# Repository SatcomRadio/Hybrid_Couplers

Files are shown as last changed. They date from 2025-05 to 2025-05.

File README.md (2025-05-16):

# Hybrid coupler boards for making circular polarization

This repo consists of different boards that use different devices to get [circular polarized](https://satcomradio.github.io/#/antennas/polarization) antennas. 

#### Please make sure to visit the [satcom radio website](https://satcomradio.github.io/) for more information

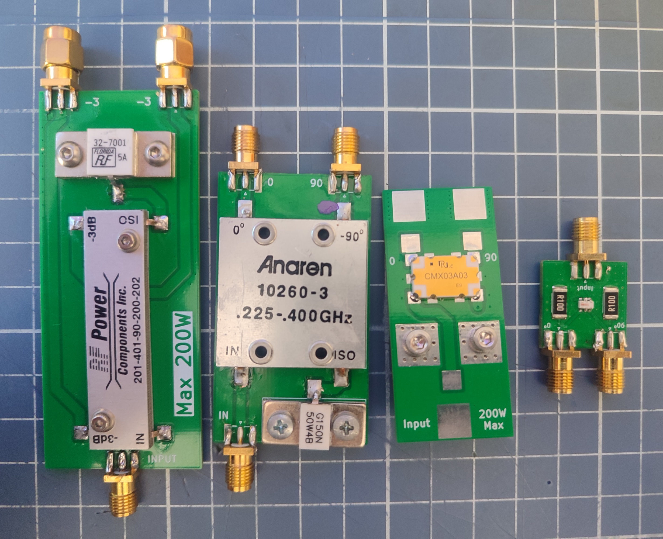
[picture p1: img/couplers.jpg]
couplers


All the PCB boards have a version that where you can use SMA connectors or soldered wires.  
If you want to use the SMA connector boards, you will need to buy:

```
3x SMA connectors for PCB with 1.6mm spacing (aliexpress.com/item/10000000835065.html)

```

Important!

You must connect them correctly! Each port has to be a "dipole".  
Depending on their orientation you will get RHCP or LHCP.

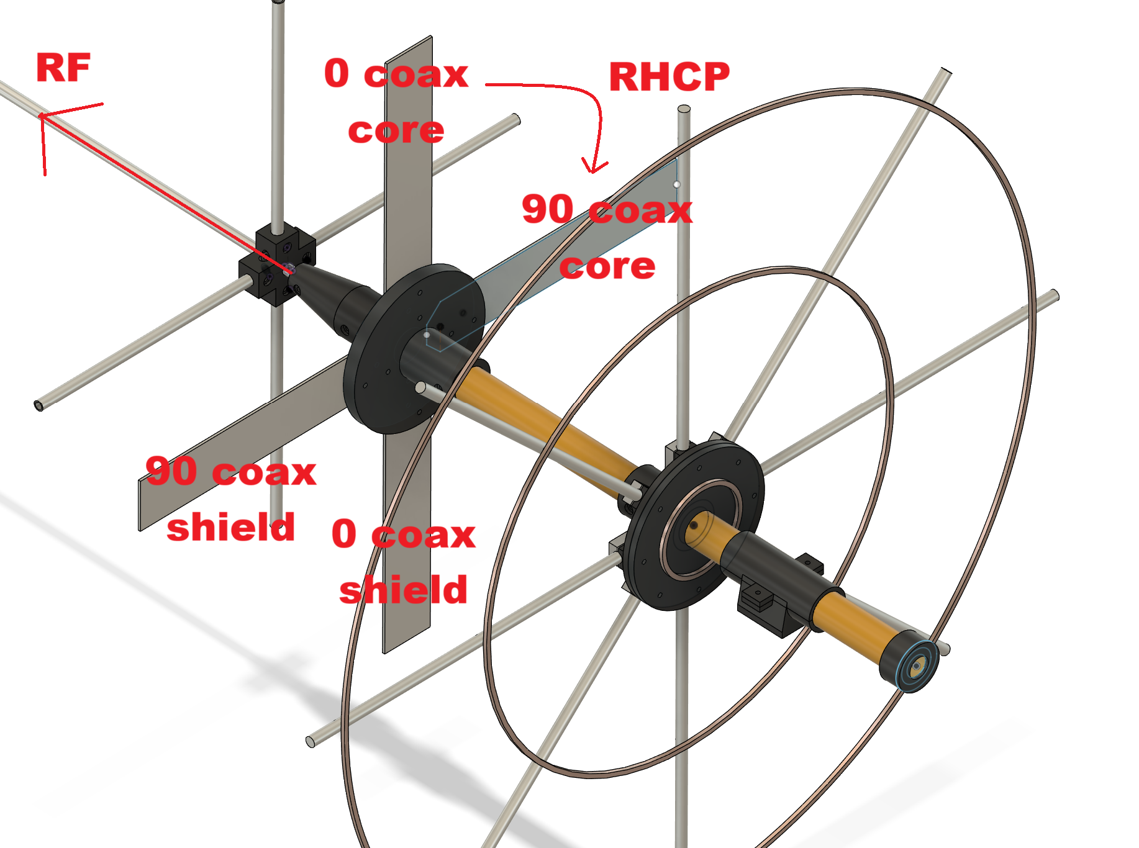
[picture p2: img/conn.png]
connection


------

## Ordering the PCB:

Download the Gerber file you want from this repo and order it a jlcpcb with the default options.  
The only option I've changed is to remove the manufacture code mark

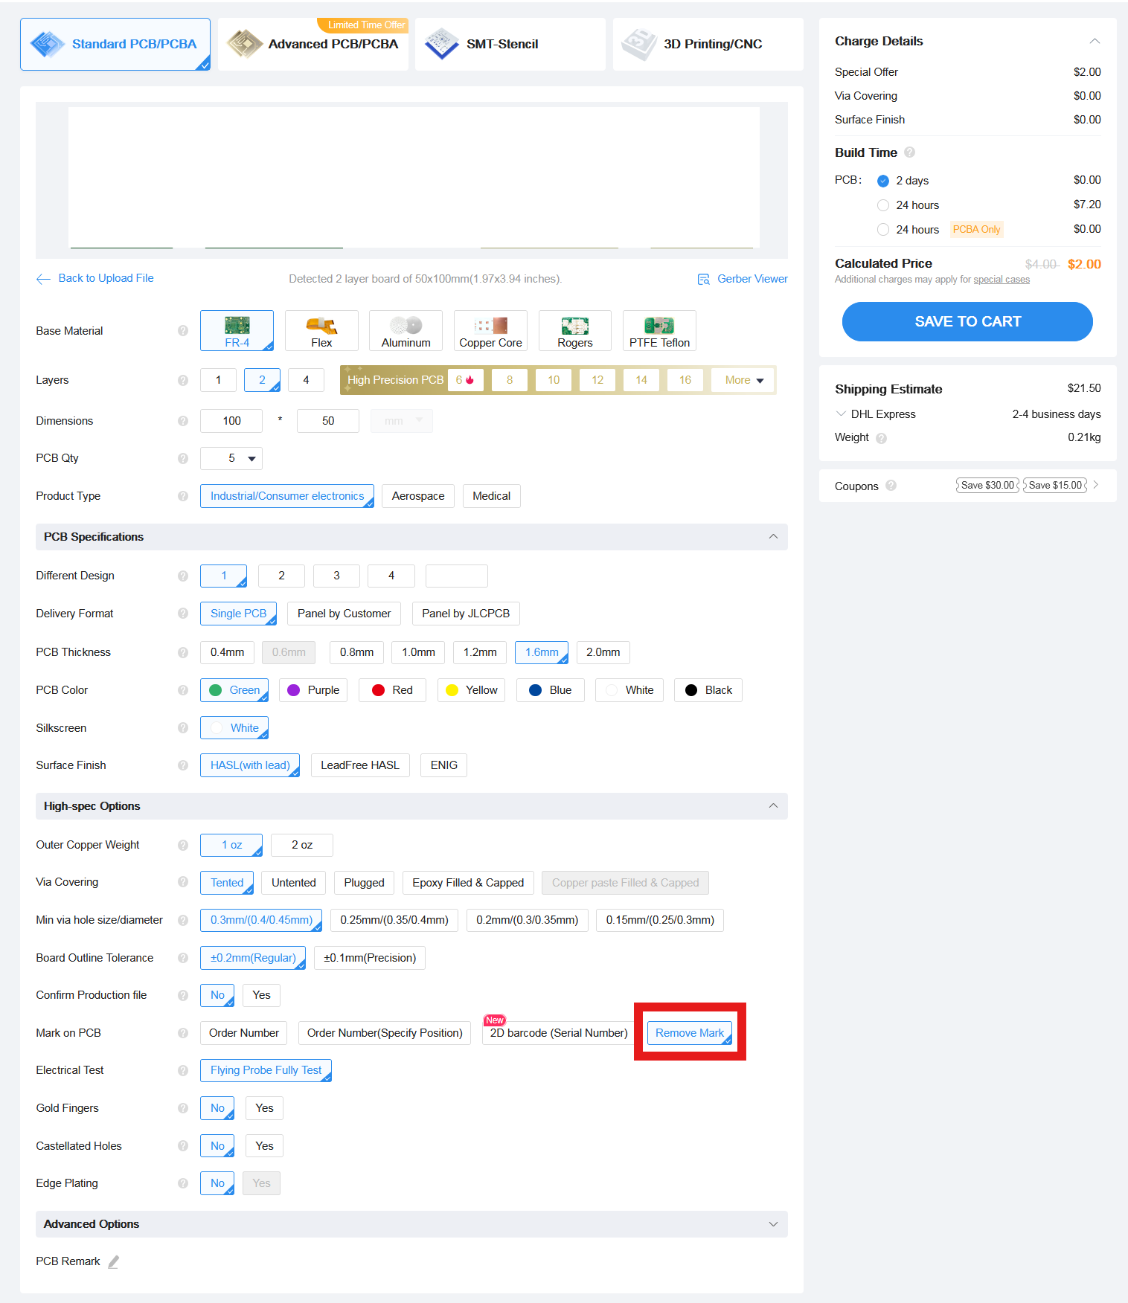
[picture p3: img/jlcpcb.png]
jlcpcb


------

## CMX03A03:

- [SMA version](./GERBER-CmxSma.zip)  
- [Soldered wires version](./GERBER-CmxRf.zip)

Most compact option for high power. Can handle 200W

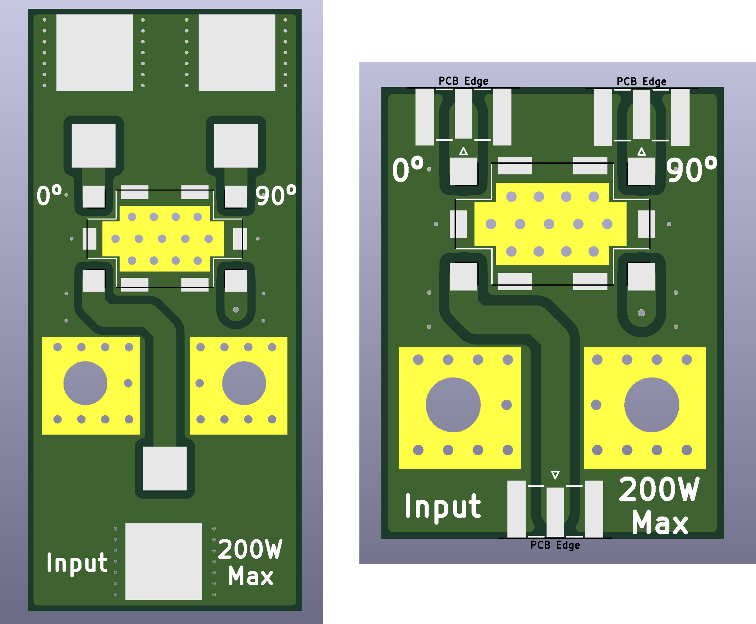
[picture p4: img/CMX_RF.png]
cmx


### BOM:

```
1x CMX03A03 (aliexpress.com/item/1005008506296292.html)
1x G150N 50 ohm RF load (aliexpress.com/item/32909755238.html)

```
----

## RF Power:

- [SMA version](./GERBER-RfPowerSma.zip)  
- [Soldered wires version](./GERBER-RfPowerRf.zip)

Can handle 200W.  
Probably an old model made by "Florida RF Labs"
There's no information about this coupler but it's usually sold with a 50 ohm resistance for free.

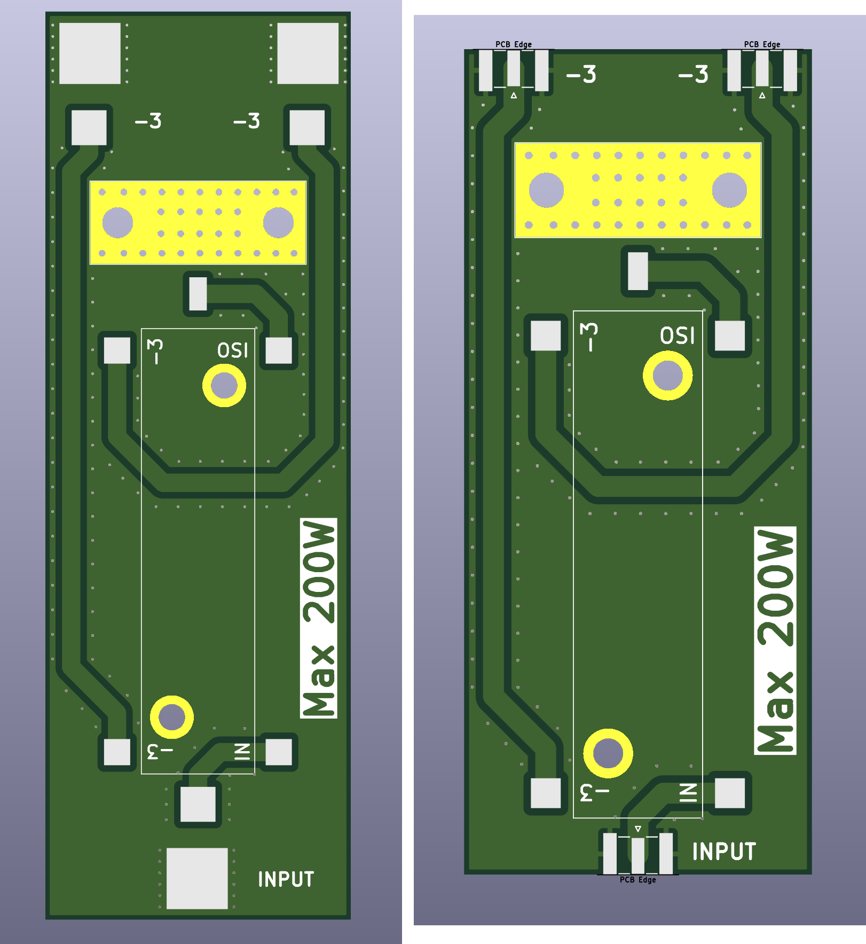
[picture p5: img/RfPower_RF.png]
rfpower


### BOM:

```
1x RF Power coupler (aliexpress.com/item/32886665884.html)

This resistance is often given for free when you buy the coupler:
1x RF 32-7001 50 ohm RF load (aliexpress.com/i/1005006266356008.html)

```
----

## Anaren 10260-3:

- [SMA version](./GERBER-AnarenSma.zip)  
- [Soldered wires version](./GERBER-AnarenRf.zip)

Can handle 250W.  
Outdated so it's difficult to find. Usually it's sold on ebay.

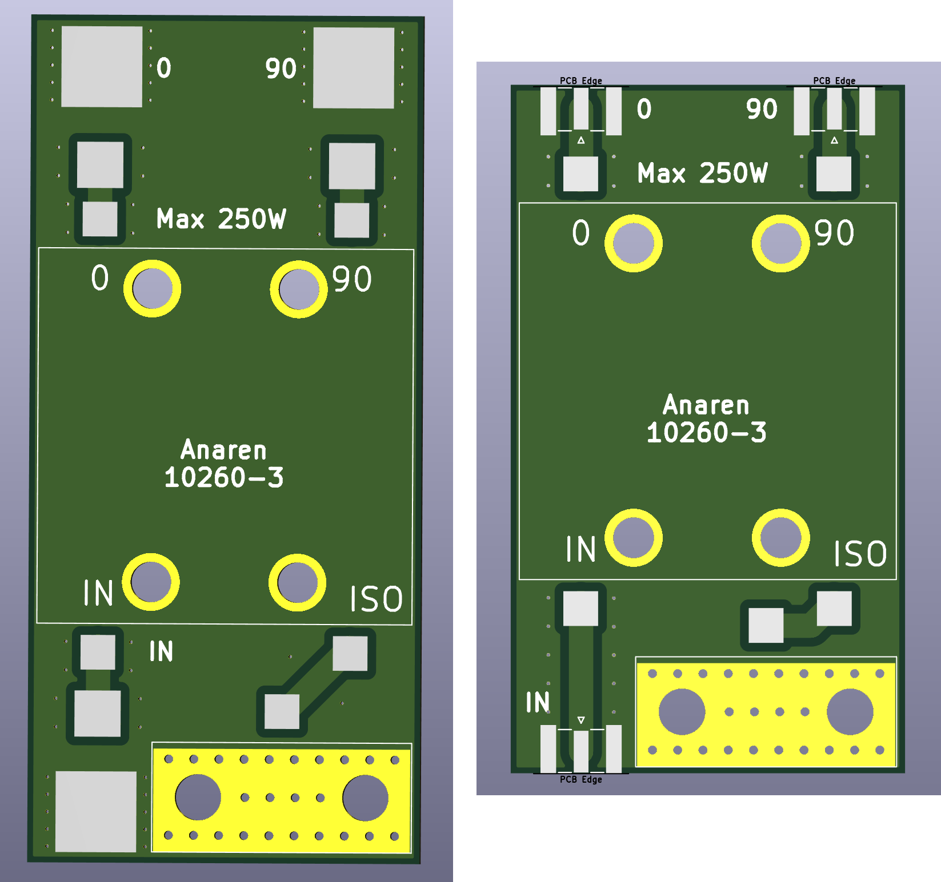
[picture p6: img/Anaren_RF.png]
anaren


### BOM:

```
1x Anaren 10260-3
1x G150N 50 ohm RF load (aliexpress.com/item/32909755238.html)

```
----

## QCN3:

- [SMA version](./GERBER-CmxSma.zip)  
- [Soldered wires version](./GERBER-Qcn3Rf.zip)

Most compact option. Can handle 15W.  
To be used only with handheld radios.

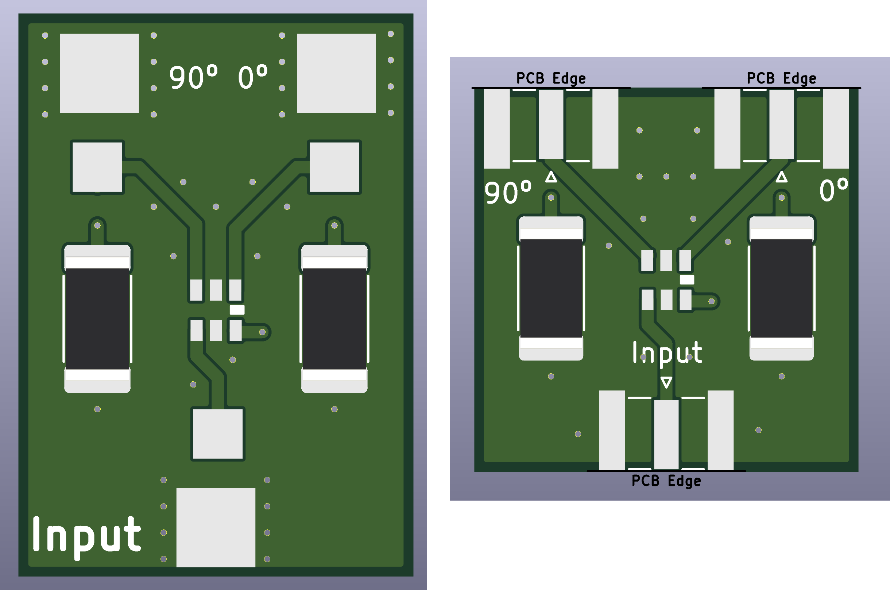
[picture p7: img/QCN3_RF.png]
qcn3


### BOM:

```
1x QCN-3 (aliexpress.com/item/1005002788551103.html)
2x SMD resistor 2512 100Ω 2W resistor (https://es.aliexpress.com/item/1005007255020731.html)

```
----

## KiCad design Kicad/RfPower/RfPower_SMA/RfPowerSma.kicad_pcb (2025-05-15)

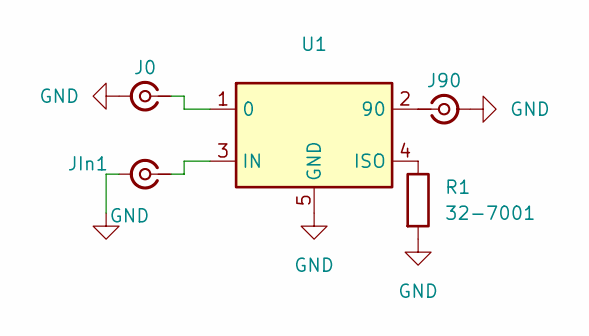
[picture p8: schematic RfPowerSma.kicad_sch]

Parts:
J0, J90: SMA_Samtec_SMA-J-P-X-ST-EM1_EdgeMount
JIn1: SMA_Samtec_SMA-J-P-X-ST-EM1_EdgeMount
R1: 32-7001
U1: RfPower

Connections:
GND: J0.2 (Ext), J90.2 (Ext), JIn1.2 (Ext), R1.2, U1.5 (GND)
unnamed: J0.1 (In), U1.1 (0)
unnamed: J90.1 (In), U1.2 (90)
unnamed: JIn1.1 (In), U1.3 (IN)
unnamed: R1.1, U1.4 (ISO)

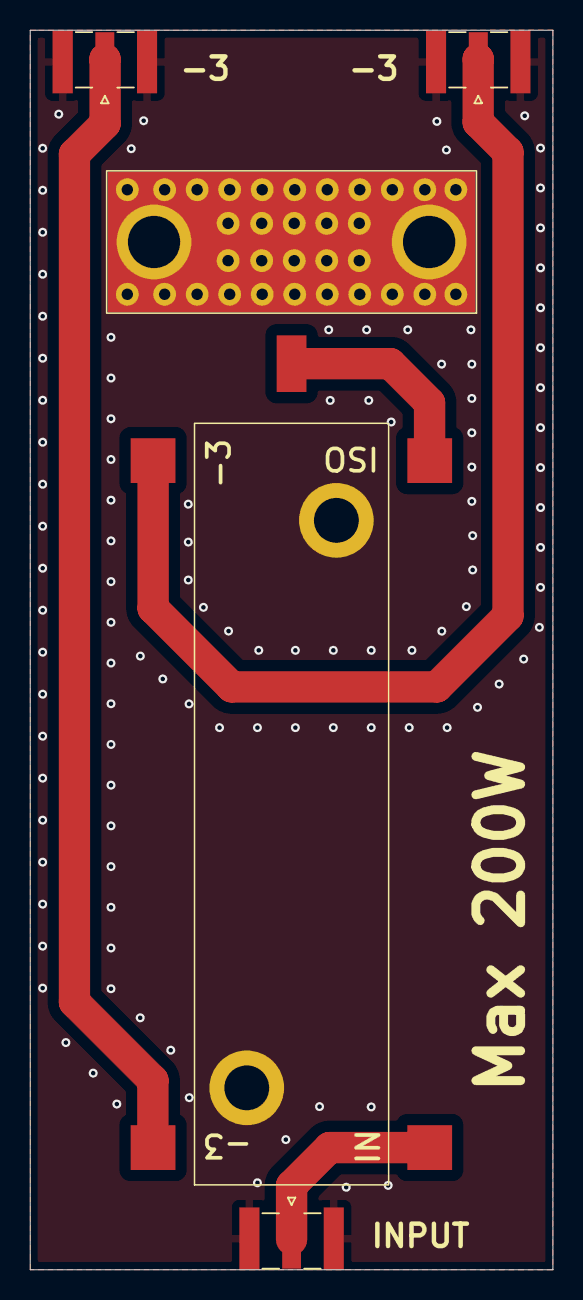
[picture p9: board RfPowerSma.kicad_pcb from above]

Board: 2 copper layers, 35.0 x 83.0 mm, 5 parts (0 on the bottom side), 5 nets.

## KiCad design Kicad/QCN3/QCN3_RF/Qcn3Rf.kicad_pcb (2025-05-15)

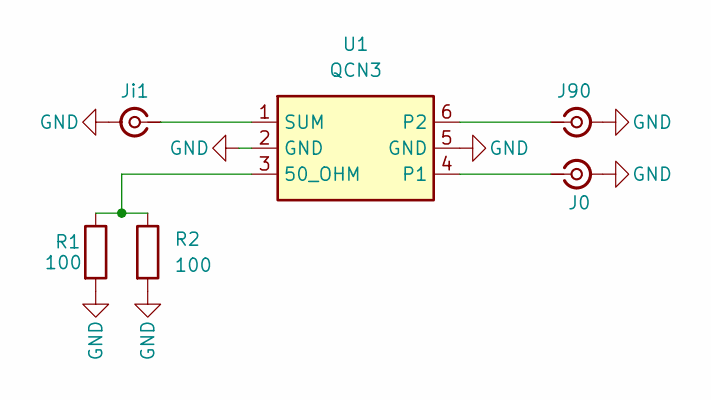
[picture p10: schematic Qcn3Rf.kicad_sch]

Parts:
J0, J90: Conn_Coaxial_Small; Wire connector_S
Ji1: Conn_Coaxial_Small; Wire connector_S
R1, R2: 100; R_2512_6332Metric_Pad1.40x3.35mm_HandSolder
U1: QCN3

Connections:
GND: J0.2 (Ext), J90.2 (Ext), Ji1.2 (Ext), R1.2, R2.2, U1.2 (GND), U1.5 (GND)
unnamed: J0.1 (In), U1.4 (P1)
unnamed: J90.1 (In), U1.6 (P2)
unnamed: Ji1.1 (In), U1.1 (SUM)
unnamed: R1.1, R2.1, U1.3 (50_OHM)

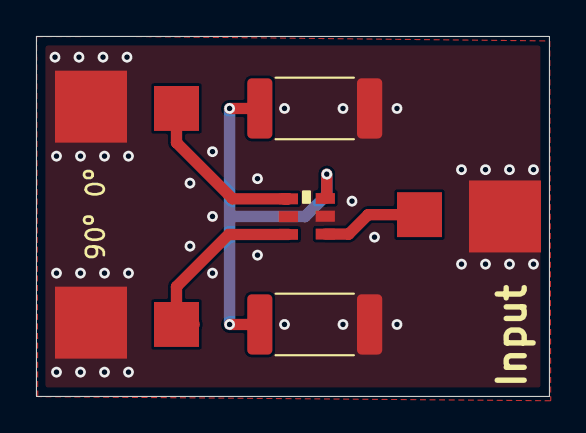
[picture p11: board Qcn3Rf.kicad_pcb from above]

Board: 2 copper layers, 28.5 x 20.0 mm, 6 parts (0 on the bottom side), 5 nets.

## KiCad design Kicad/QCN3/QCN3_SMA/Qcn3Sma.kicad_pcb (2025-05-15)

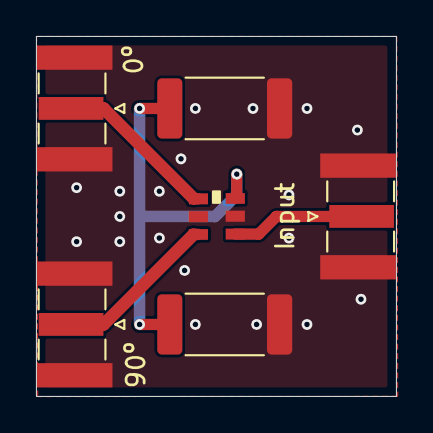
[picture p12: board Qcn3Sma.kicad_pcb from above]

Board: 2 copper layers, 20.0 x 20.0 mm, 6 parts (0 on the bottom side), 5 nets.

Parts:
0º, 90º: Conn_Coaxial_Small; SMA_Samtec_SMA-J-P-X-ST-EM1_EdgeMount
Input: Conn_Coaxial_Small; SMA_Samtec_SMA-J-P-X-ST-EM1_EdgeMount
R1, R2: 100; R_2512_6332Metric_Pad1.40x3.35mm_HandSolder
U1: QCN3

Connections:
GND: 0º.2 (Ext), 90º.2 (Ext), Input.2 (Ext), R1.2, R2.2, U1.2 (GND), U1.5 (GND)
unnamed: 0º.1 (In), U1.4 (P1)
unnamed: 90º.1 (In), U1.6 (P2)
unnamed: Input.1 (In), U1.1 (SUM)
unnamed: R1.1, R2.1, U1.3 (50_OHM)
